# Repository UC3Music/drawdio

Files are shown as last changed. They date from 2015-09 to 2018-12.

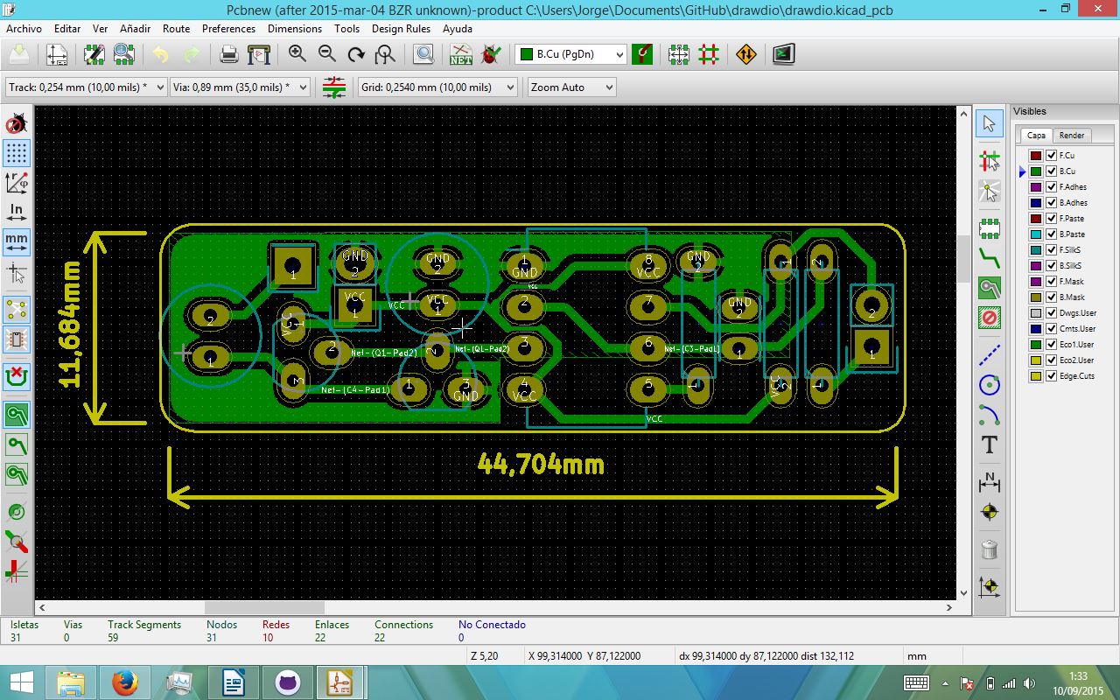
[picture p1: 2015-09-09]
media/drawdioV0.1.JPG

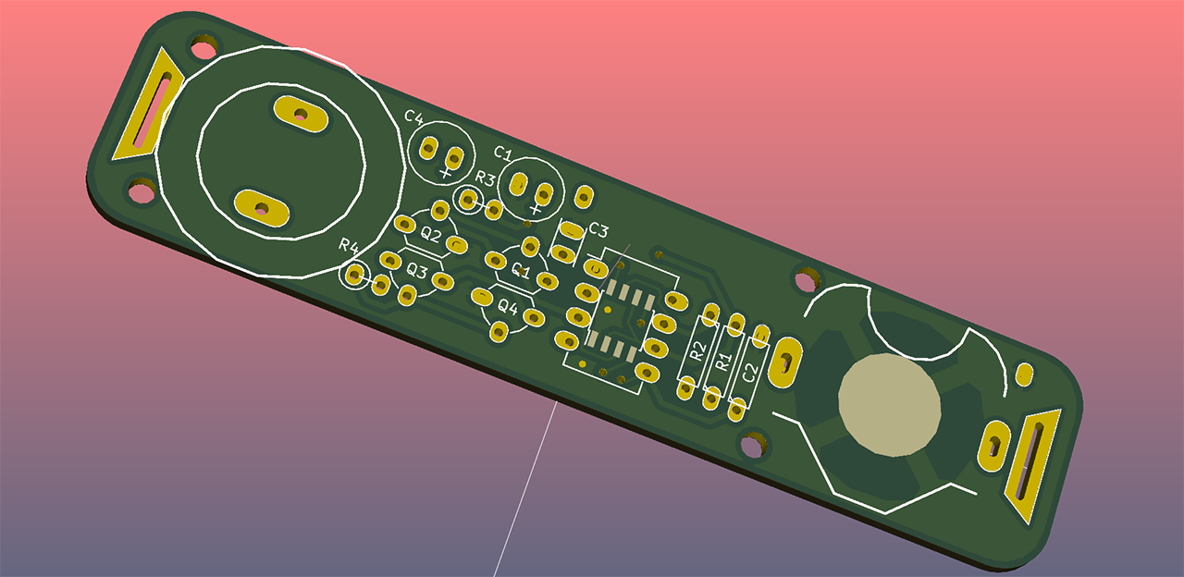
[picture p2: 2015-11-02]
media/drawdioV1.0.png

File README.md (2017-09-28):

# Drawdio

UC3Music version of Drawdio, originally designed by Jay Silver

Double side copper board, big and spacy pads (ready for first-time soldering)

*Uc3Music's enchancement: New output stage to provide twice output voltage and raise volume.*

---------------------------------------

Versión UC3Music del Drawdio, diseñado originalmente por Jay Silver

PCB de doble cara, pads grandes y espaciados (facil de soldar por noveles)

*Mejora de UC3Music: nueva etapa de salida que proporciona el doble de voltaje de salida para conseguir más volumen de salida.*

<p align="center">

</p>

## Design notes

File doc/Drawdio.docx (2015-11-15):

# Drawdio

Por JorFru, UC3Music

# El proyecto

Drawdio=Draw+Audio

El Drawdio es un pseudo-instrumento musical, diseñado originalmente por Jay Silver en el MIT (http://web.mit.edu/). El proyecto original se aloja aquí: Drawdio MIT (http://web.media.mit.edu/~silver/drawdio/), aunque existe mejor documentación en Adafruit (https://learn.adafruit.com/drawdio/overview), ya que esta empresa ha absorbido el proyecto con fines comerciales (http://www.adafruit.com/category/28).

Construí un Drawdio el año pasado y me encantó su sencillez. Por eso quería traerlo a vosotros, para que comprobéis lo sencilla que es la electrónica y pillaseis el gusanillo del D.I.Y.

Además del diseño original de Jay, he añadido una etapa de salida mejorada para que suene.

# Utilización

Hacer sonar el Drawdio es muy sencillo: tan solo haz un circuito entre sus dos electrodos. Los electrodos son los terminales con forma de trapecio en los extremos del Drawdio. El aparato “leerá” la impedancia (otra forma de llamar a la resistencia eléctrica) de tu circuito te dará una frecuencia proporcional a ésta.

El Drawdio está montado sobre un lápiz, de forma que hace muy fácil crear circuitos con tus dibujos, ya que el grafito conduce la electricidad. Otras maneras de hacerlo sonar son: pintando con agua y un pincel, con plantas, con un círculo de mucha gente, un grifo de agua… en realidad cualquier cosa medianamente conductiva. Y digo medianamente porque si utilizáis un material que conduzca realmente bien la electricidad no notaréis cambios en la afinación, como por ejemplo algo metálico. El Drawdio funciona con impedancias muy altas, desde megaohmios hasta gigaohmios, es decir, poco conductivos. Materiales que ofrezcan resistencias de pocos ohmios no aportarán demasiado a cambiar la nota. Resultan ser los materiales que tienen una conductividad parecida a la del agua (que ofrece mucha resistencia aunque no lo creas) o que están formados en su mayoría por agua, como puede ser el cuerpo humano.

Para que os hagáis una idea de en qué valores nos estamos moviendo doy unos datos:

- Resistencia del cuerpo humano: 2,000,000 Ohmios entre extremidades.
- Resistencia de la mina del lápiz: 10 Ohmios
- Resistencia de 1cm de dibujo con lápiz apretando: 5,000,000 Ohmios
- Resistencia de 1cm de dibujo con lápiz sin apretar: 20,000,000 Ohmios

# Cómo funciona

Utiliza el famoso circuito integrado 555, en su versión de bajo voltaje con tecnología CMOS. El modelo en particular es TLC555CP, fabricado por Texas Instruments. Esta versión de bajo voltaje nos permita hacerlo funcionar desde 1V, entonces con una pila convencional AAA (1.5V) nos funcionará perfectamente.

El circuito integrado 555 es un temporizador que se utiliza en una variedad de aplicaciones y se aplica en la generación de pulsos y de oscilaciones. El 555 puede ser utilizado para proporcionar retardos de tiempo, como un oscilador, y como un circuito integrado flip-flop, según cómo se diseñe el circuito alrededor de él.

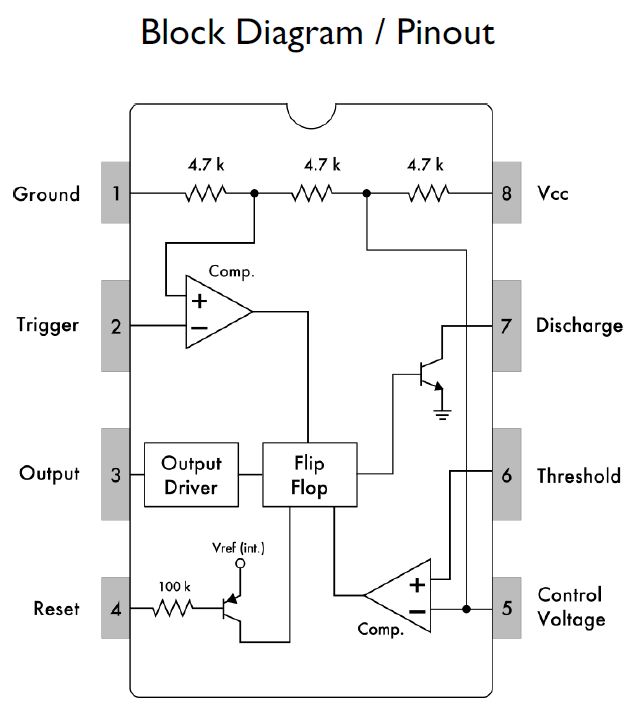
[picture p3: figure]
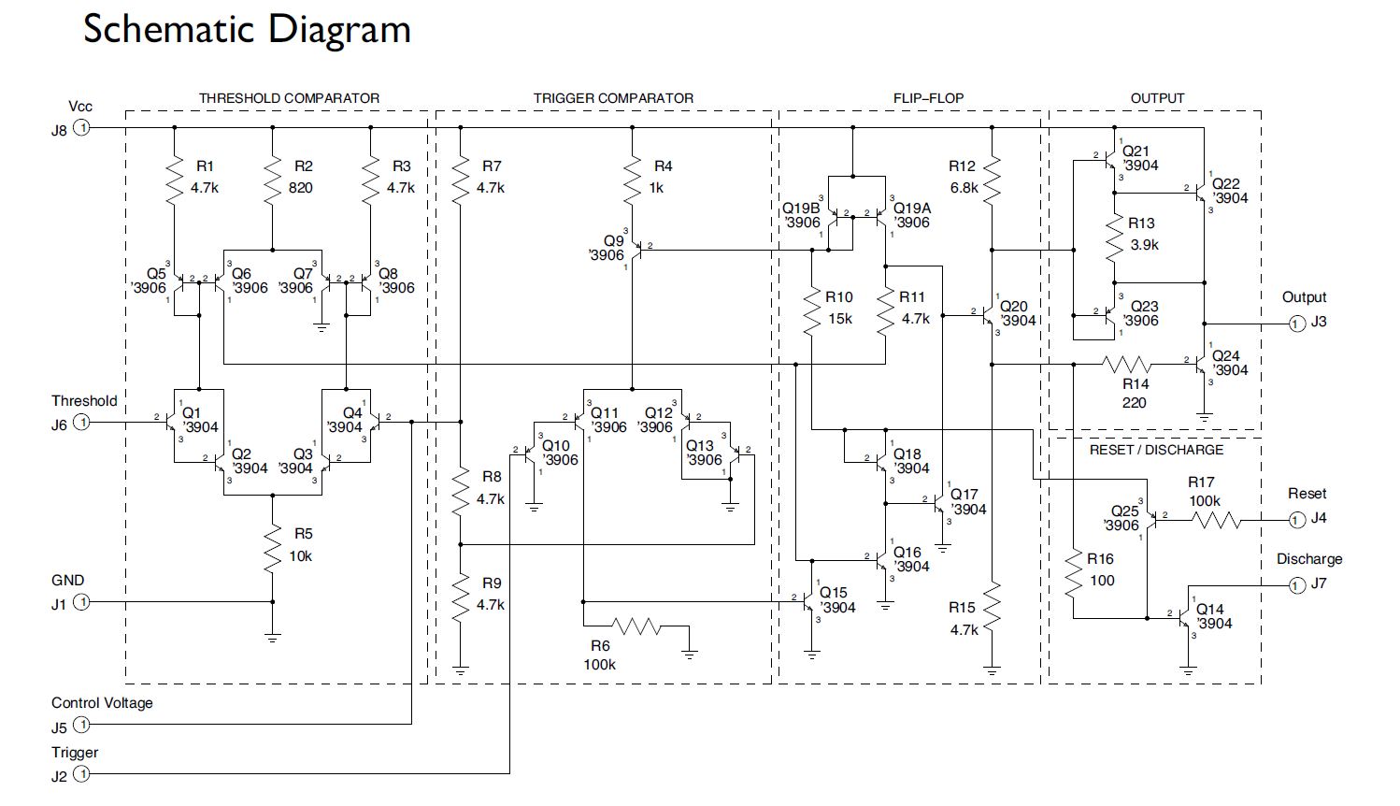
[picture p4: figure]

Utilizaremos su modo de funcionamiento astable. Y en la práctica esto nos proporcionará una onda cuadrada a la salida, cuya frecuencia viene dada por:

Donde C es 680x10^-12, R1 es 10x10^3 y R2 es la resistencia del circuito que dibujemos más 300x10^3. Y esto nos dará rangos de frecuencia audibles con los materiales antes mencionados.

La amplitud de la onda es fija, por lo que no podremos ajustar el volumen.

En realidad, lo que estará ocurriendo es que cargamos y descargamos un condensador. Cada ciclo de la onda es una carga y descarga de este condensador, que es el que se llama C3 en nuestra placa, y su valor es 680pF. La velocidad a la que esto ocurre está regulada por dos componentes electrónicos: el condensador en sí y una resistencia que regula la corriente a través de él. Para hacer la frecuencia variable podemos dejar un parámetro fijo y mover el otro. Podríamos hacer el condensador variable (algo parecido a lo que hace el Theremin), o podemos hacer la resistencia variable, que es más sencillo, como es el caso del Drawdio.

Cuanta más resistencia pongamos, más despacio circulará la corriente, más despacio será el ciclo de carga y descarga, más largo será el periodo y por lo tanto más baja será la frecuencia, es decir, un sonido grave. Por el contrario, si el dibujo es corto, con poca resistencia, la electricidad fluirá más rápido, cargando y descargando el condensador más rápidamente, reduciendo el periodo de la onda y por lo tanto más alta la frecuencia, produciendo un sonido agudo.

# Para qué sirve cada componente electrónico

En nuestra placa tenemos un componente activo y varios pasivos.

- Bichito de 8 patas: es el susodicho LMC555CN. Este nos produce una onda cuadrada cuya parte alta son 1.5V (voltaje de alimentación) y la parte baja es 0V (masa).
- R1: resistencia de 330K, regula la frecuencia más alta que puede reproducir nuestro Drawdio en “cortocircuito”. Conseguimos limitar las frecuencias altas a 3kHz (usando la ecuación). Un sonido demasiado agudo podría ser molesto (más aún)
- R2: resistencia 10K, regula la curva de frecuencia vs. resistencia del dibujo.
- R3 y R4, valor de 1K: controlan el consumo de los transistores. Evitan sobrecalentamiento y consumo excesivo. Habría que recalcular su valor para trabajar con pilas de diferente valor que 1.5V.
- C1: Condensador de 470uF. Condensador de desacople, consigue mantener estable el voltaje de nuestra fuente de alimentación. Nuestro aparato consume mucha electricidad en los flancos de la onda cuadrada. La pila no responde bien a rápidas descargas de energía. La pila alimenta de forma continua al condensador, que funciona como almacenamiento de apoyo momentáneo mientras se produce el consumo alto del flanco. Sin este condensador, es posible que el chip se apagase en los flancos.
- C2: Condensador de 680pF. Este es el condensador que se carga y descarga a la frecuencia del sonido. Un valor más grande producirá siempre sonidos más graves, y viceversa.
- C3: Condensador de 100nF. Controla parte de la forma de onda, pero no afecta mucho.
- C4: Condensador de 470uF. Aísla la corriente continua de nuestro altavoz, lo cual lo protege. Un valor más pequeño que el ofrecido reducirá la potencia consumida y cambiará el timbre del sonido. Un valor más grande lo hará sonar más parecido a una onda cuadrada pero consumirá bastante más energía sin sonar mucho más alto, ya que un altavoz tan pequeño sólo hace ruido en los flancos. Con el valor actual la forma de onda es aproximadamente una onda de sierra.

# Formas de onda:

A la salida del 555 (izquierda). En los bornes del altavoz (derecha)

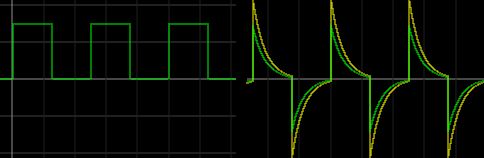
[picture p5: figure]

Sin condensador C4 la forma de onda de salida sería la siguiente: Consumiríamos más potencia (área bajo la curva) pero no se notará el incremento de volumen porque el altavoz no tiene fuerza suficiente. Sin condensador C4, aun sin estar sonando, el consumo del Drawdio sería alto y gastaríamos la batería si nos la dejásemos puesta. Además de poder fastidiar el altavoz.

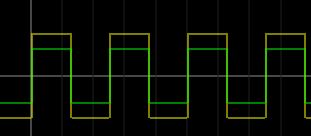
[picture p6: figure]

# Etapa de salida

Como veis en las fotos de formas de onda, hemos conseguido duplicar el voltaje de salida. El 555 a solas produciría voltajes de entre 0 y 1.5V, entonces tendríamos un voltaje efectivo de 1,5Vp-p para mover el altavoz.

Con mi etapa de salida en modo puente se consiguen 3Vp-p a partir de una pila de 1.5V, lo cual lo hace sonar más alto. Y este circuito tiene esta pinta. A la izquierda,cuando el 555 nos da una salida baja (0V), y a la derecha cuando la salida es alta (1.5V). Nota: se ha retirado el condensador para poder mostrar de forma más fácil los voltajes con los colores.

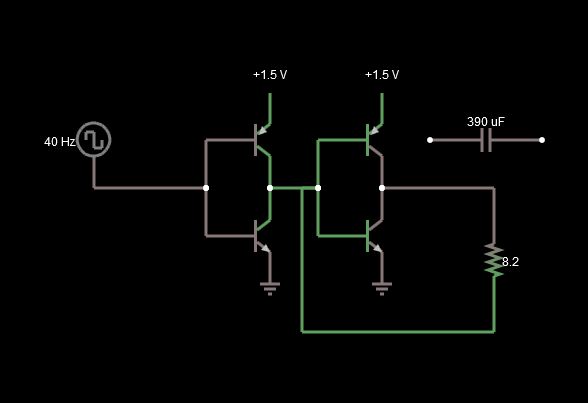
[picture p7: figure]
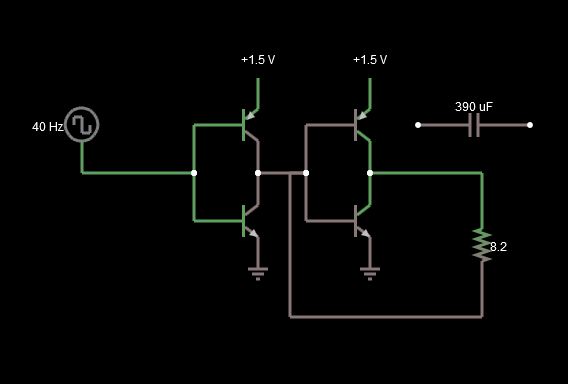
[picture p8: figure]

En estas simulaciones, los cables de color verde son los que tienen un voltaje alto, al menos 1V. Y en gris los cables con voltaje 0V.

La configuración que he elegido se parece mucho a los Puente en H que se emplean para controlar el movimiento adelante/atrás de los motores de corriente continua. Este circuito tiene dos estados. Uno cuando la salida del 555 es alta y otra para cuando es baja. En el primer caso, el altavoz verá voltaje en su patilla inferior, y cero en la superior, produciendo la potencia correspondiente a este voltaje (P=V^2/R -> 1.5^2/8=0.3W). En el segundo caso, el altavoz verá voltaje en su patilla superior y cero en la inferior, produciendo otra vez la misma potencia (0.3W)

Esta es la etapa de salida de un Drawdio convencional, y produce esta forma de onda. La parte negativa que se ve en la forma de onda la produce el condensador descargándose.

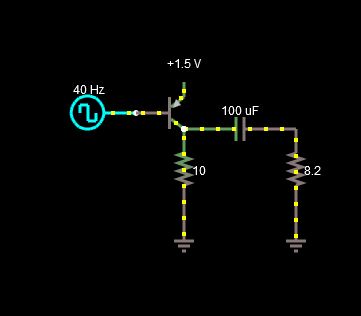
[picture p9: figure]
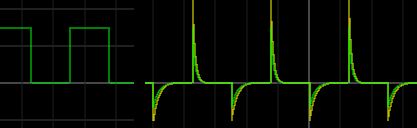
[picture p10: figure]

El diseño tradicional sólo aporta potencia en la mitad del ciclo. Aunque con el condensador, que nos guarda el voltaje, también podemos exprimir un poquito por la parte de abajo. Sin el condensador, la salida sería así: Es decir, la misma que la de entrada pero invertida, debido a la configuración del transistor. Entonces sólo produciría potencia la mitad del tiempo.
La salida en puente empuja el altavoz y también tira de él, lo que hace un movimiento más amplio y al final consigue sonar más alto, con un voltaje de alimentación limitado.

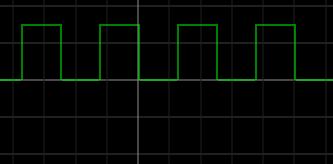
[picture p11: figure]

# La pila de botón

Como podrás comprobar, hay un hueco muy grande reservado para poner una pila de botón, con los agujeros preparados para soldar el soporte. Las pilas de botón suelen tener 3V, entonces, ¡en el altavoz conseguiríamos sonar como si tuviésemos 6V! Y parece genial a primera vista, porque la pila es más pequeña, encaja perfecta en la placa y no sobresale de manera exagerada. Y pese haber probado otros Drawdios tradicionales con pilas de botón (incluso dos en serie: 6V) y hacerlo sonar muy alto… con esta tecnología de etapa de salida hacemos que circule bastante corriente, y esto lleva las pilas do botón al límite.

Duplicar el voltaje en el altavoz hará que circule el doble de corriente (por I=V/R). Y ocurrirá que el consumo de potencia sea cuatro veces más (por P=V^2/R), cosa que una pila más pequeña no soportará. Lo que podremos hacer es sustituir el condensador C4 por otro de valor más pequeño, e intentar producir el consumo grande sólo en los flancos, soportando esta descarga por el condensador de apoyo C1, que puede entregar potencia de manera rápida. Recordad también que posiblemente tengamos que cambiar las resistencias de los transistores para limitar el consumo excesivo.

Las pilas de botón están pensadas para descargarse a lo largo de años, como en los relojes, mandos a distancia… cosas que consuman poco. Y tienen una impedancia de salida alta, la cual nos limita la corriente entregada y nos baja el voltaje, haciendo que con 3V suene incluso más bajo que con las de 1.5V.

Y como no tuve oportunidad de probar un prototipo antes del taller, decidí no arriesgarme y utilizar la pila AAA de toda la vida, de eficacia probada y barata. Más adelante, con algo de tiempo, pensaré en cómo utilizar todo el voltaje de las pilas de botón y hacerlo sonar más macarra.

Fuentes:

http://shop.evilmadscientist.com/productsmenu/tinykitlist/652

https://es.wikipedia.org/wiki/Circuito_integrado_555

Toda la documentación “oficial” la encontrarás en el repositorio de este proyecto: https://github.com/UC3Music/drawdio

Visita también la wiki: https://github.com/UC3Music/drawdio/tree/master/media/Wiki

El proyecto es opensource, siéntete libre de difundirlo, mejorarlo, jugar con ello…

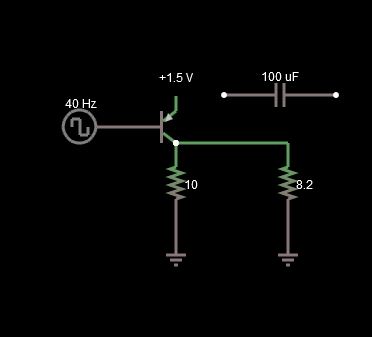
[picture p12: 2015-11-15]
media/Wiki/Capturadcd.JPG

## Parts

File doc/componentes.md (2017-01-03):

# Condensadores
* C1 470uF
* C2 0.1uF
* C3 680pF
* C4 470uF

# Resistencias
* R1 330K o similar
* R2 10K
* R3, R4 1K

# Transistores
* Q2, Q4 BC547
* Q1, Q3 BC558/7

# Otros
* Muelle del portapilas hacia el lado contrario del altavoz
* Altavoz sin polaridad

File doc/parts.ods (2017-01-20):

Qty | Part | Ref. In board | Description | Unit Cost | Cost
1 | http://es.rs-online.com/web/p/altavoces-en-miniatura/7243100/ | SPK | Speaker | 1,185
1 | http://es.rs-online.com/web/p/circuitos-temporizadores/6624677/ | U1 | IC – oscillator | 0,872
1 | http://es.rs-online.com/web/p/soportes-accesorios-de-montaje-para-baterias/2794959/ | BT1 | Battery holder | 1,75
1 | http://es.rs-online.com/web/p/zocalos-dil/7020654/ | -- | Socket IC | 0,358
1 | http://es.rs-online.com/web/p/products/7605037/ | -- | Battery | 0,649
2 | http://es.rs-online.com/web/p/products/7037453/ | C1, C4 | Electrolytic condenser | 0,24
2 | http://es.rs-online.com/web/p/transistores-bipolares/7969704/ | Q2, Q4 | NPN Transistor | 0,035
2 | http://es.rs-online.com/web/p/transistores-bipolares/8031147/?searchTerm=803-1147 | Q1, Q3 | PNP Transistor | 0,028
1 | http://es.rs-online.com/web/p/resistencias-fijas-de-orificio-pasante/0149105/ | R1 | Resistor 330K | 0,014
1 | http://es.rs-online.com/web/p/resistencias-fijas-de-orificio-pasante/6832709/ | R2 | Resistor 10K | 0,016
2 | http://es.rs-online.com/web/p/resistencias-fijas-de-orificio-pasante/6833165/ | R3, R4 | Resistor 1K | 0,016
1 | http://es.rs-online.com/web/p/condensadores-ceramicos-monocapa/6832115/ | C3 | Capacitor 680pf – 681 | 0,074
1 | http://es.rs-online.com/web/p/condensadores-ceramicos-monocapa/7215240/ | C2 | Capacitor 0.1uF - 104 | 0,081
1 |  |  | Pencil 2B or softer | 0,35

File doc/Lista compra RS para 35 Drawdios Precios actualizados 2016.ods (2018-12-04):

Cosa que es | Precio unitario | múltiplo de compra (o mínimas unidades de compra) | cantidad a comprar | Precio compra |  | COPIA Y PEGA | Referencia RS | cantidad a comprar
Transistor tipo-pincha | 0.49 | 100 | 100 | 4.9 |  |  | 761-9831 | 100
Transistor tipo-nopincha | 0.48 | 100 | 100 | 4.8 |  |  | 761-9822 | 100
Soporte pila | 1.67 | 1 | 35 | 58.45 |  |  | 279-4959 | 35
Paquete 12 pilas | 3.69 | 1 | 3 | 11.07 |  |  | 744-2209 | 3
Altoparlante | 1.2 | 2 | 36 | 43.2 |  |  | 724-3100 | 36
Timer IC | 1.8 | 5 | 35 | 63 |  |  | 662-4677 | 35
Condensador electrolítico 470uF | 0.44 | 25 | 75 | 33 |  |  | 703-7453 | 75
Resistencia 330K | 0.14 | 10 | 100 | 1.4 |  |  | 149-105 | 100
Resistencia 10K | 0.39 | 20 | 100 | 3.9 |  |  | 125-1164 | 100
Resistencia 1K | 0.38 | 20 | 100 | 3.8 |  |  | 125-1159 | 100
Condensador cerámico 680pF | 202 | 25 | 50 | 10.1 |  |  | 683-2115 | 50
Condensador cerámico 0.1uF | 0.2 | 5 | 50 | 10 |  |  | 538-1310 | 50
Condensador electrolítico 470uF | 0.38 | 10 | 30 | 7.6 |  |  | 708-3825 | 30
Cinta cobre | 0 |  |  | 0 |  |  | 542-5460 | 1
PCB | 1 | 30 | 30 | 30€ | recomiendo PCBWay, SeeedStudio, Boktech, 123PCB

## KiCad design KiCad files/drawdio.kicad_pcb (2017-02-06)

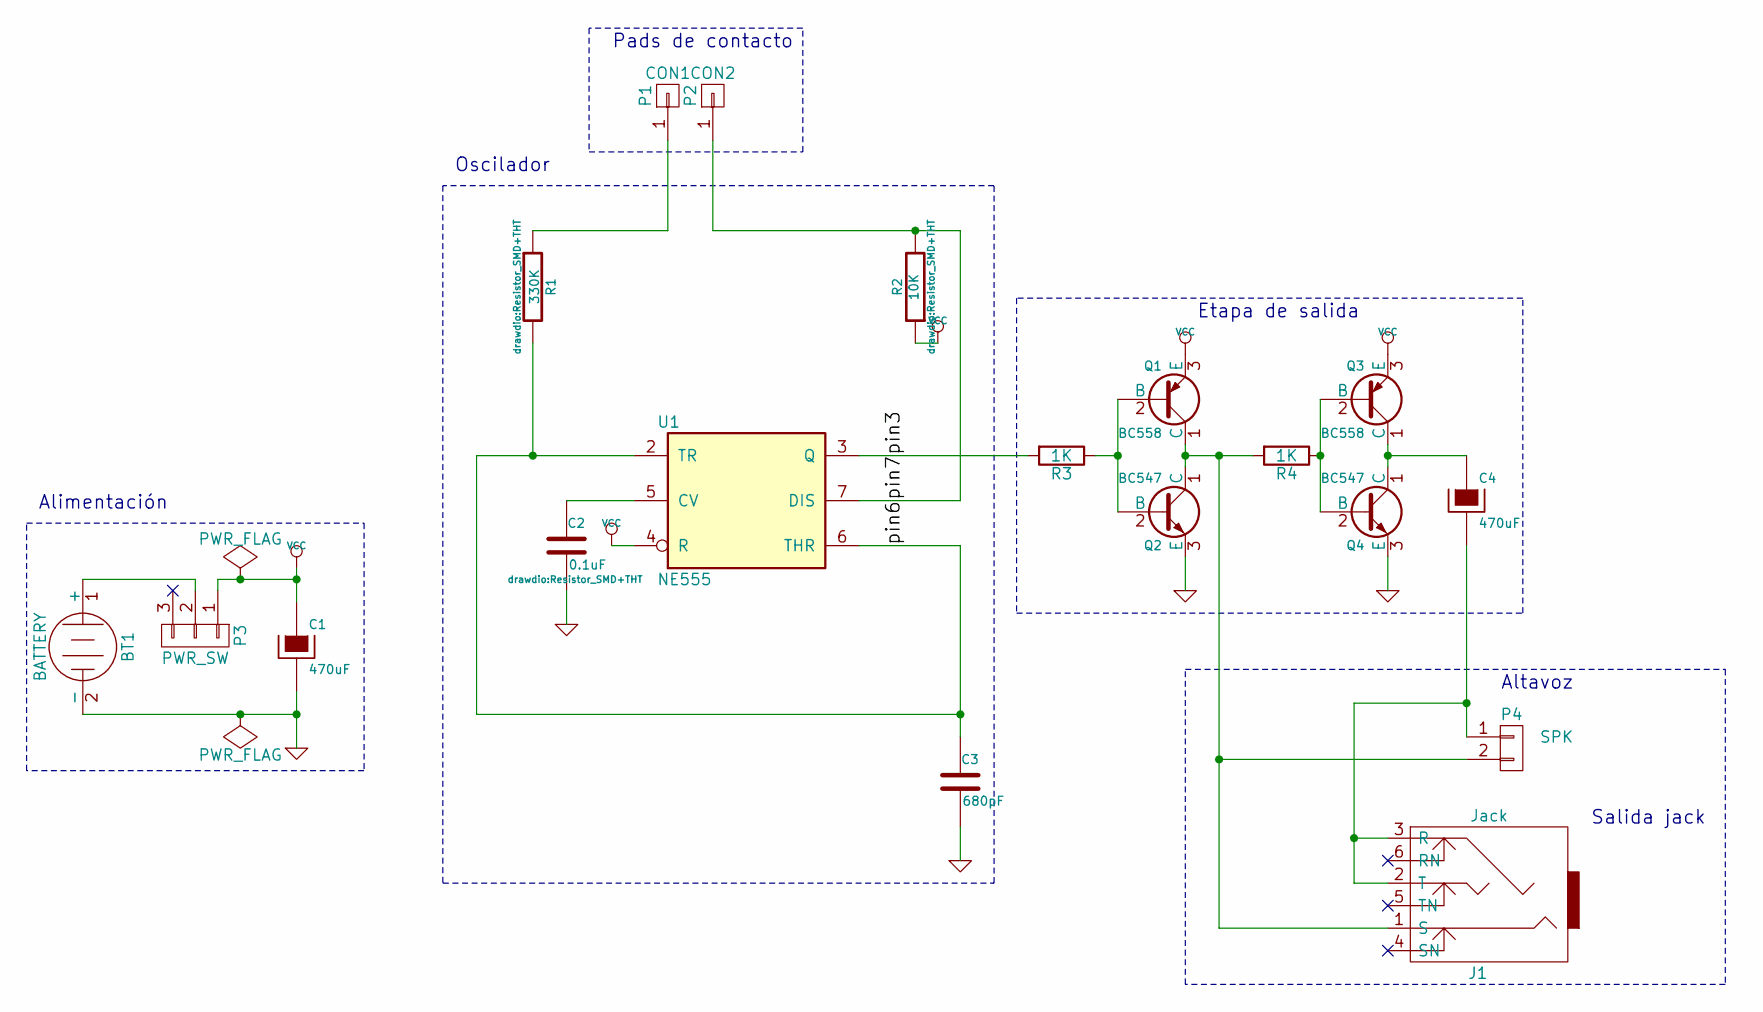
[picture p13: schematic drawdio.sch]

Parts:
BT1: BATTERY; AAA_cell_holder
C1, C4: 470uF; Elko_vert_11.2x6.3mm_RM2.5
C2: 0.1uF; Resistor_SMD+THT
C3: 680pF; Resistor_SMD+THT
J1: Jack; jack_barato
P1: CON1; Drawdio_conn
P2: CON2; Drawdio_conn
P3: PWR_SW; PWR_SW_Drawdio_SS-12D00(1P2T)
P4: SPK; RS_mini_speaker_724-3100
Q1, Q3: BC558; TO-92_JorFru_compact
Q2, Q4: BC547; TO-92_JorFru_compact
R1: 330K; Resistor_SMD+THT
R2: 10K; Resistor_SMD+THT
R3, R4: 1K; Resistor_SMD+THT
U1: NE555; DIP8+SOIC8_2

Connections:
/pin3: R3.2, U1.3 (Q)
/pin6: C3.1, R1.2, U1.2 (TR), U1.6 (THR)
/pin7: P2.1, R2.2, U1.7 (DIS)
GND: BT1.2 (-), C1.2, C2.2, C3.2, Q2.3 (E), Q4.3 (E), U1.1 (GND)
unnamed 4: BT1.1 (+), P3.2; also elsewhere on the board
unnamed: C2.1, U1.5 (CV)
unnamed: C4.1, Q3.1 (C), Q4.1 (C)
unnamed: C4.2, J1.2 (T), J1.3 (R), P4.1
unnamed: J1.1 (S), P4.2, Q1.1 (C), Q2.1 (C), R4.2
unnamed: P1.1, R1.1
unnamed: Q1.2 (B), Q2.2 (B), R3.1
unnamed: Q3.2 (B), Q4.2 (B), R4.1
VCC: C1.1, P3.1, Q1.3 (E), Q3.3 (E), R2.1, U1.4 (R), U1.8 (VCC); also elsewhere on the board

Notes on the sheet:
Altavoz
Etapa de salida
Alimentación
Pads de contacto
Oscilador
Salida jack

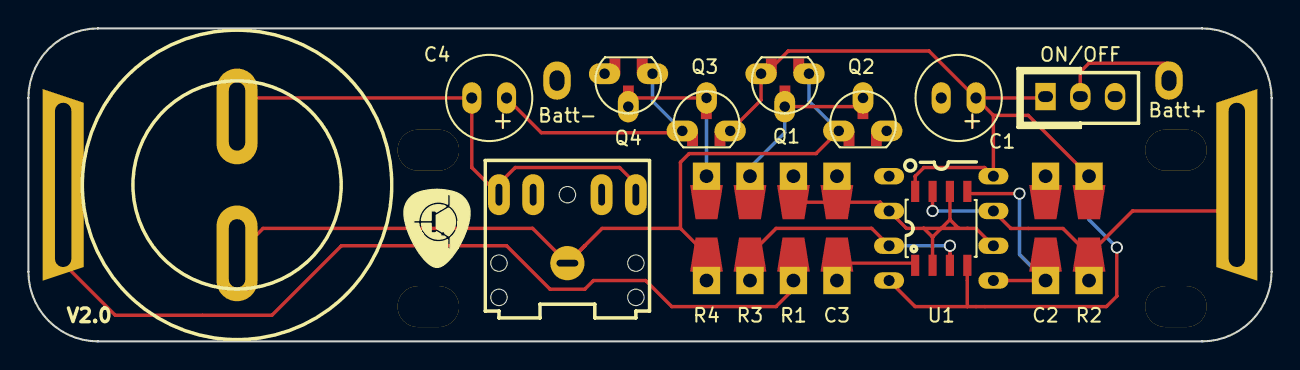
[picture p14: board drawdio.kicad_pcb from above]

Board: 2 copper layers, 90.8 x 22.9 mm, 20 parts (0 on the bottom side), 13 nets.

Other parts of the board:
ON/OFF: PWR_SW; PWR_SW_Drawdio_SS-12D00(1P2T)
SPK: LOGO; Fiducial_1mm_Dia_2.54mm_Outer_CopperTop

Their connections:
unnamed 4: ON/OFF.2; also elsewhere on the board
VCC: ON/OFF.1; also elsewhere on the board

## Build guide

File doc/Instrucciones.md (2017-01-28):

#Construcción de tu Drawdio
¡Enhorabuena, vas a comenzar a construir tu Drawdio!

Te recomendamos que empieces colocando los componentes más pequeños, por ejemplo las resistencias y los condensadores C2 y C3.
También es buena idea comenzar por los componentes menos sensibles al calor, si es tu primera vez soldando. Estos son las resistencias y los conectores. Los que deberías dejar para el final son los transistores, circuitos integrados y condensadores electrolíticos.
Usar un zócalo para tu chip 555 es muy recomendable, y es una de las piezas por las que puedes empezar.

#Componentes

## Condensadores
* C1 470uF Electrolítico polarizado (Un valor entre 47 y 470uF funcionará bien).
* C2 0.1uF Cerámico o de película. 104 pone escrito en el condensador. Sin polaridad.
* C3 680pF Cerámico. 681 pone escrito. Sin polaridad.
* C4 470uF Electrolítico (Un valor entre 47 y 470uF funcionará bien)

## Resistencias
* R1 330K o similar
* R2 10K
* R3, R4 1K (colocados en vertical en la versión V1.0)

## Transistores
* Q2, Q4 BC547 o cualquier transistor NPN
* Q1, Q3 BC558/7 o cualquier transistor PNP

## Otros
* Muelle del portapilas hacia el lado contrario del altavoz. En la versión V2.0 se montará en dirección contraria, pero viene indicado en la placa.
* Altavoz sin polaridad

#¿Cómo soldar?
Permíteme añadir los siguientes trucos, espero que te sirvan!

##- Regla #1 y única: *¡El estaño sólo se pega en los metales calientes!*
Si tú quieres unir el pad (zona metálica que rodea el agujero) con la patilla del componente, has de calentar los dos metales de manera uniforme: pad y patilla, más o menos a la temperatura de fusión del estaño.
Un truco personal mio es poner el soldador tocando el pad y la patilla a la vez, haciendo un poco de presión. Y añadir el estaño por el otro lado: el detalle es que el estaño no toque directamente el soldador.
De esta manera el estaño sólo se derretirá una vez que los metales a unir estén a la temperatura adecuada. Si tocas con el estaño directamente en la punta del soldador, éste se derretirá muy alegremente, pero patilla y pad puede que no estén calientes: entonces no se pegarán bien los metales, de hecho incluso se pueden repeler si están demasiado fríos.

##Tiempos: 
- Calentar pad y patilla: entre 1 y 2 segundos.
- Añadir estaño: durante 1 segundo.
- Retirar estaño y soldador a la vez.
Según esta aproximación, una soldadura debería de llevarte como mucho 3 segundos. Si han pasado más de tres segundos y no has conseguido derretir el estaño lo mejor sería abortar misión, dejar enfriar un poco las cosas durante cinco segundos y volver a intentarlo. Todo esto a fin de evitar que los componenten se calienten más de lo debido y/o se derritan.
Ya verás que fácilmente se le pilla el tranquillo y podrás hacer soldaduras en medio segundo o menos.

##Cantidad de estaño:
Lo ideal sería dejar una montañita con forma de volcán por el lado que estás soldando y que el estaño llegue al otro lado de la placa a través del agujero. Si te pasas de montañita no pasa nada, dejará de tener forma de volcán y comenzará a tener forma de esfera.
Si usas un estaño fino (0.5mm) necesitarás entre 1 y 2cm para rellenar un agujero. Si tu estaño es más grueso (1mm) necesitarás entre 2.5mm y 5mm para rellenarlo.
Si tu estaño es sospechosamente grueso (2mmm), es posible que sea estaño de fontanero, el cual no te funcionará demasiado bien.

#Buena suerte!

Para cualquier duda puedes ponerte en contacto con nosotros en el siguiente mail: uc3music@gmail.com

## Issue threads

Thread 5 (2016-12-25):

Enhancements observed in workshops

David-Estevez, 2016-12-25:
These are several possible improvements for Drawdio observed during the development of workshops:

* [x] More spacing between resistor pads
* [x] Better polarity indication for IC
* [x] Larger holes for zip ties
* [x] Larger slot for copper strip
* [x] Location of C3 is ambiguous
* [x] Battery holder is very hard to insert in holes
* [x] Battery holder polarity is not indicated in silkscreen
* [x] Q1 silkscreen is hard to read (due to via hole)

JorFru, 2017-02-09:
Todo resuelto en https://github.com/UC3Music/drawdio/commit/0b4b8f43eea45b36ef9ca76c592d2b332f47224a

David-Estevez, 2017-02-09:
:clap: :clap: :clap:

Closed 2017-02-09.

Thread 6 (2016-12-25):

Drawdio: casta-free version

David-Estevez, 2016-12-25:
Develop Drawdio that does not require RS components.

David-Estevez, 2017-04-09:
Creo que ab0cc41 by @JorFru cierra esta issue

JorFru, 2017-04-09:
No estoy seguro de cerrarla bródel!
Actualmente la placa acepta más modelos de altavoces, porque he dejado unas
ranuras grandes para cualquier espaciado entre pines: digamos que el
hardware está terminado.
Pero todavía falta encontrar un altavoz más disponible y más barato que el
de RS. Ese es el reto anti-casta.
Digamos que la issue se ha transformado de un problema de hardware a un
problema de investigación y documentación.

On Apr 9, 2017 19:33, "David Estévez Fernández" <notifications@github.com>
wrote:

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

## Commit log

2015-06-16 prototipo versión amatacaballo
    [drawdio.kicad_pcb]
2015-06-16 gerbers add
    [drawdio.kicad_pcb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]
2015-09-05 Bigger pads for easier soldering
    [drawdio.kicad_pcb]
2015-09-05 Trigged size
    [drawdio.kicad_pcb]
2015-09-07 smaller board
    [drawdio.kicad_pcb]
2015-09-10 Fix ugly track
    [drawdio.kicad_pcb]
2015-09-10 Add GND plane in front layer
    [drawdio.kicad_pcb]
2015-09-18 Fixed ugly traces
    [drawdio.kicad_pcb]
2015-09-18 Update gerbers
    [drawdio-B_Cu.gbl, drawdio-B_Mask.gbs, drawdio-Edge_Cuts.gbr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]
2015-10-19 Heavy work
    [_saved_drawdio.sch, drawdio.kicad_pcb, drawdio.sch]
2015-10-19 Added holes
    [_saved_drawdio.sch, drawdio.kicad_pcb, drawdio.sch]
2015-10-27 Añadidas resistencias
    [$drawdio.sch, drawdio.kicad_pcb, drawdio.sch]
2015-10-27 AAA cell added
    [drawdio.kicad_pcb, drawdio.sch]
2015-10-27 Pre-release 1.0
    [drawdio.kicad_pcb]
2015-10-28 Reviewed and ready
    [drawdio-B_Cu.gbl, drawdio-B_Mask.gbs, drawdio-B_SilkS.gbo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]
2015-10-28 Gerbers sent
2015-11-15 Wiki is coming
    [drawdio.sch]
2015-11-15 files moved to folders
    [drawdio.kicad_pcb, drawdio.sch]
2017-01-20 schematic upgrades
    [drawdio.sch]
2017-01-20 added parts lists with links to RS casta-todavia
    [parts.ods]
2017-01-23 Checkpoint, a dormir!
    [drawdio.kicad_pcb, drawdio.sch]
2017-01-23 Adeed Jack
    [_saved_drawdio.sch, drawdio.kicad_pcb]
2017-01-25 puede que funcione
    [drawdio.kicad_pcb, drawdio.sch]
2017-01-25 Mounting holes
    [drawdio.kicad_pcb]
2017-01-26 Casi terminado
    [_saved_drawdio.sch, drawdio.kicad_pcb]
2017-01-27 añadidas silkscreen. Letras y numerajos
    [_saved_drawdio.sch, drawdio.kicad_pcb, drawdio.sch]
2017-01-27 añadidos gerber
    [drawdio-B.Cu.gbl, drawdio-B.Mask.gbs, drawdio-B.SilkS.gbo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]
2017-01-27 minucias en la silkscreen, resubiendo gerber
    [drawdio-B.Cu.gbl, drawdio-B.Mask.gbs, drawdio-B.SilkS.gbo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]
2017-01-27 tenia errores el gerber
    [drawdio-B.Cu.gbl, drawdio-B.Mask.gbs, drawdio-B.SilkS.gbo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]
2017-01-27 presentable V2.0
    [drawdio-B.Cu.gbl, drawdio-B.Mask.gbs, drawdio-B.SilkS.gbo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]
2017-02-06 Retocado el tamaño de algunas silkscreen
    [drawdio-B.Cu.gbl, drawdio-B.Mask.gbs, drawdio-B.SilkS.gbo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]
